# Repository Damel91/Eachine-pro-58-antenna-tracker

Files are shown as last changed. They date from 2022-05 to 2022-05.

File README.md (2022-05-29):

# Eachine-pro-58-antenna-tracker
A RSSI antenna tracker based on the eachine pro58

Tracker brain is the source for the arduino nano

wifi_firmware is the source for the esp8266

Into the PCB folder you can find the PCB wich is ready to use with the press and peel tecnique,
also you can find the pinout of the eachine pro 58

The 3D folder is a mess, go to thingiverse to find the freecad file to modify the project and see the entire project perspective https://www.thingiverse.com/thing:5397986/files

This antenna tracker is based on PID controller and single antenna tracking is experimental so use the manual settings

To configure the tracker use the GUI app that you need to install into your android smartphone

The project is designed also to work with a bmp280 module connected to the i2c bus

The analog pin of the ESP8266 is used to read the battery voltage, so use a trimmer to calibrate the voltage,
some esp8266 analog pin have 1V max others 3,3V, use the jumper to disconnect the trimmer output from the analog pin and calibrate the maximum voltage with the maximum level for the esp8266

The step down module can work from 2S LIPO to 6S LIPO and the code will automatically recognize the battery status and it's cell number, but of course you need to calibrate the trimmer with the maximum level of a 6S LIPO.

The gui will connect to the esp8266 through wifi since the esp8266 is configured as ap.

The antenna tracker mover vertically and horizzontally(wich is applied the actual pid tracking)

The servos used are two 9g

Also you need three 624ZZ ball bearings

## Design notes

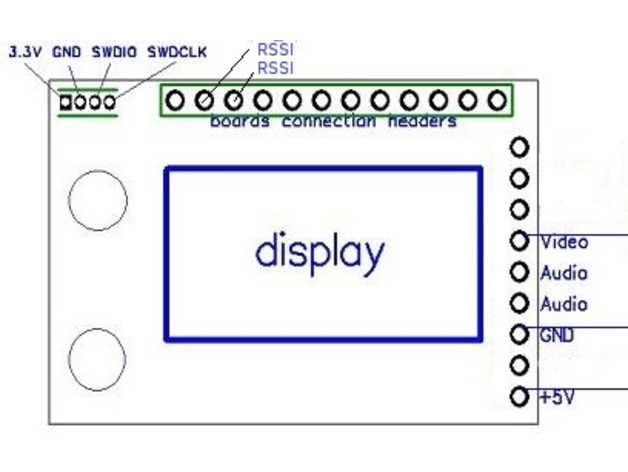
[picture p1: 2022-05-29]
PCB/eachine pro 58 pinout.jpg

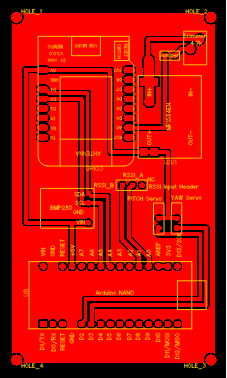
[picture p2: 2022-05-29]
PCB/PCB_antenna tracker_bottom_and_silk.png

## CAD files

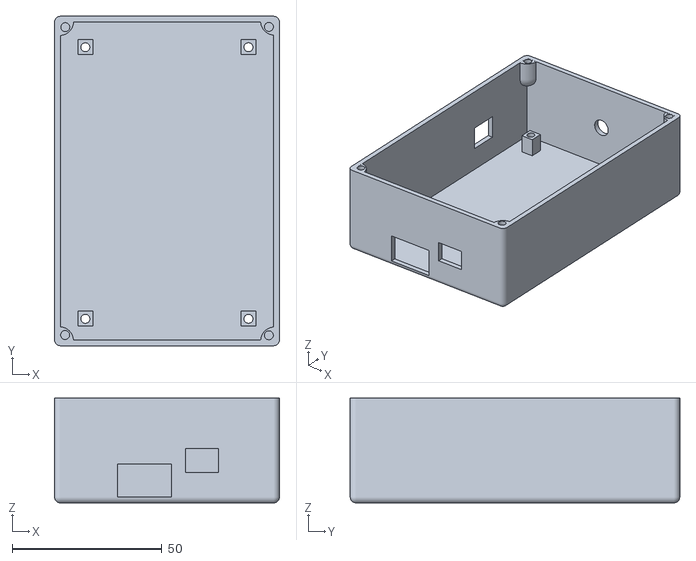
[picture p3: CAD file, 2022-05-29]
tracker 3d/tracker design-main box.stl
75.1 x 110.0 x 35.0

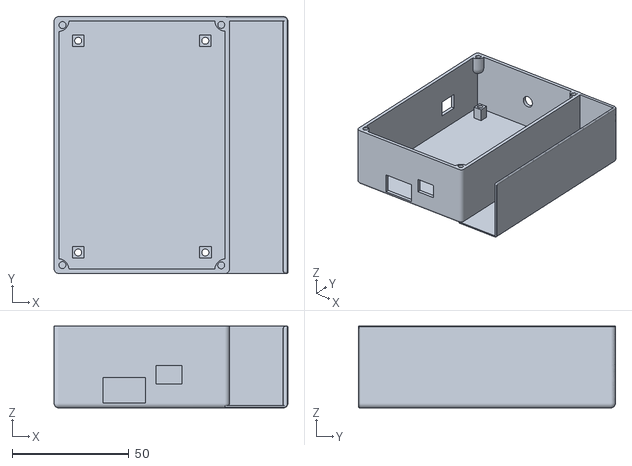
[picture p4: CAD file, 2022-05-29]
tracker 3d/tracker design-main box and battery holder.stl
100.1 x 110.0 x 35.0

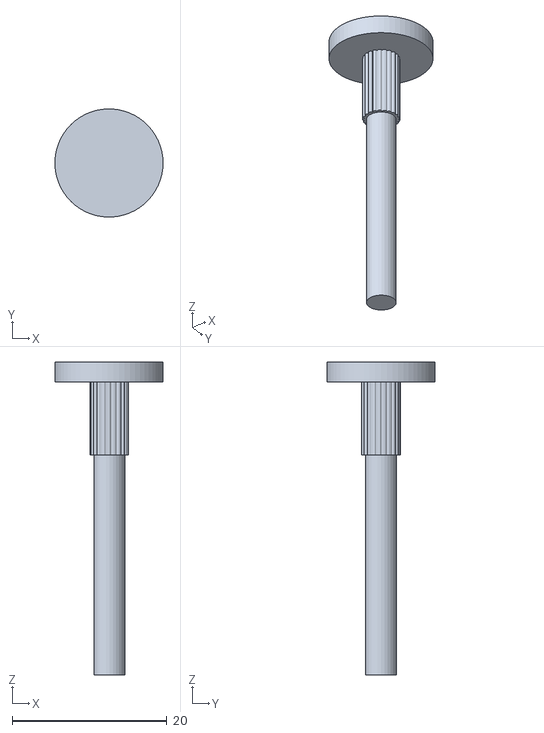
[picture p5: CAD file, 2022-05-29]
tracker 3d/tracker design-crankshaft_v2.stl
14.0 x 14.0 x 40.5

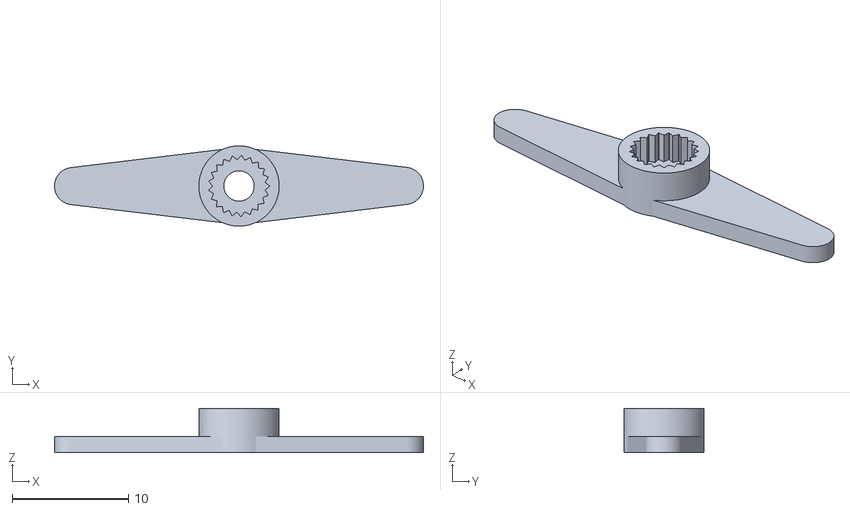
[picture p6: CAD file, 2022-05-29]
tracker 3d/SG90_Servo_Horn-4.stl
31.7 x 6.90 x 3.82

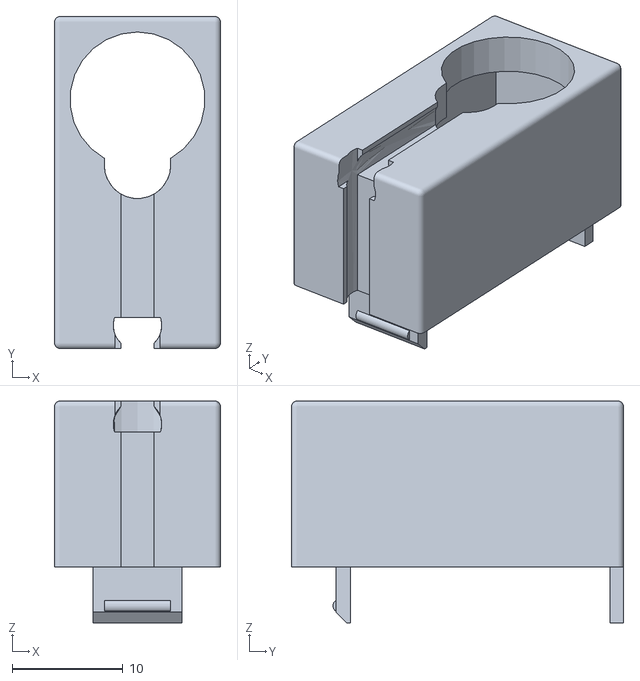
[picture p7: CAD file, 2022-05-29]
tracker 3d/Top_without_pegs_v21.stl
15.0 x 30.0 x 20.1

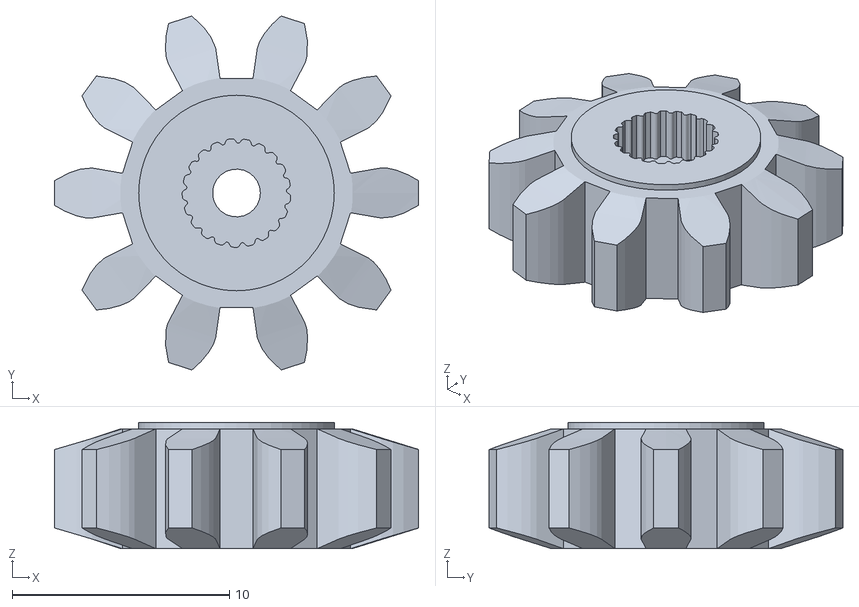
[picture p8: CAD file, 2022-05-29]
tracker 3d/03_Gear_Z10_adapter_v2.stl
16.8 x 16.3 x 5.80

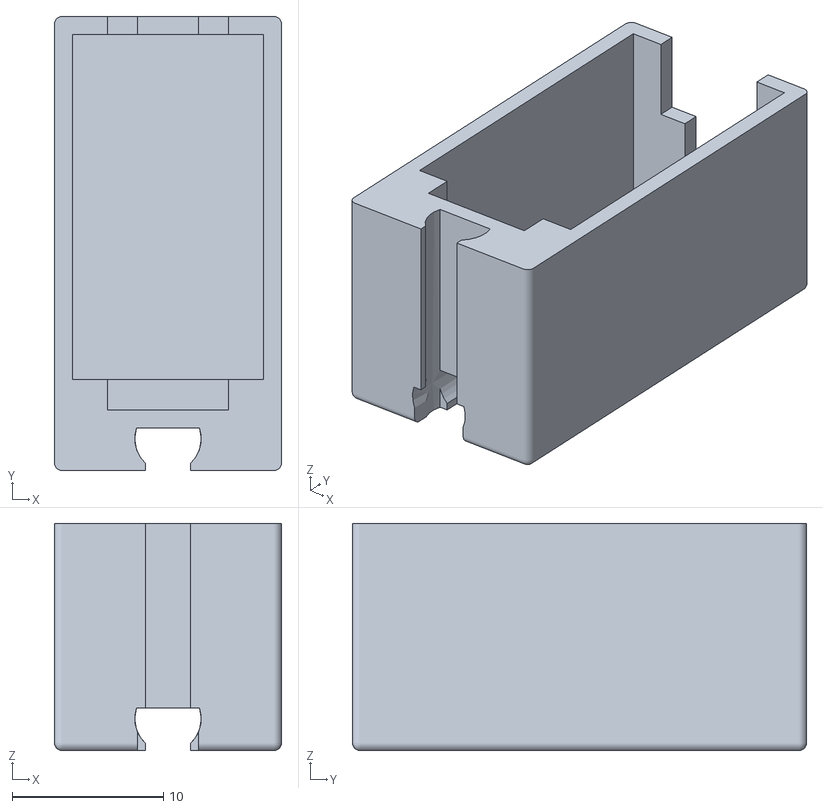
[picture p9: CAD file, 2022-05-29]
tracker 3d/Bottom_without_pegs_v21.stl
15.0 x 30.0 x 15.0

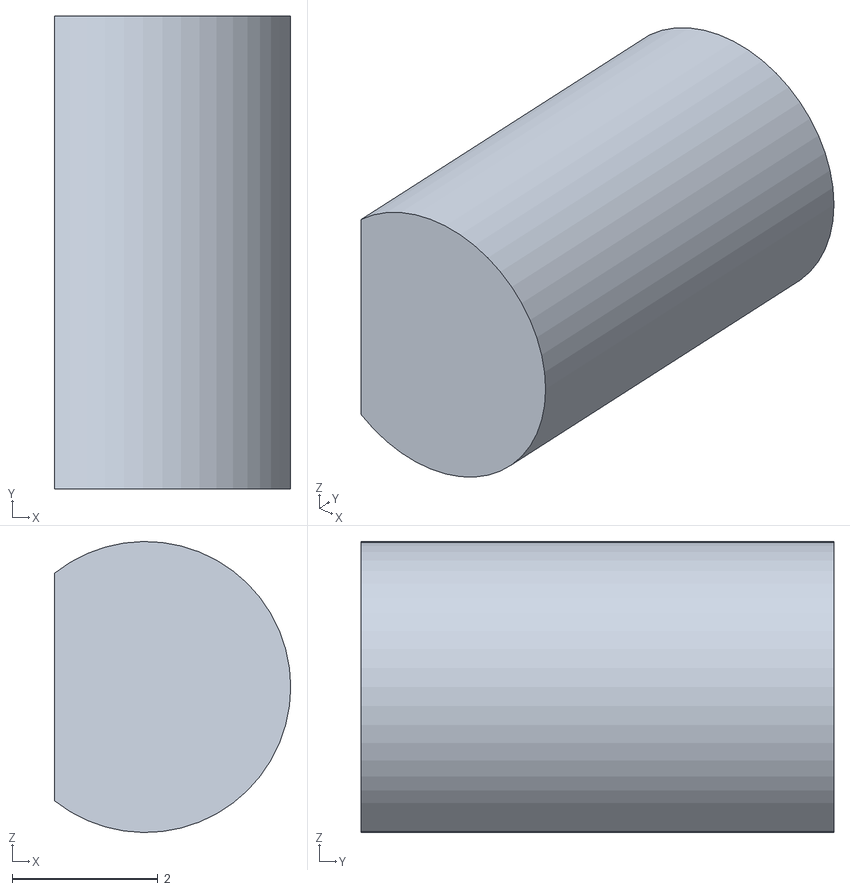
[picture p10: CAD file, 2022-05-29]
tracker 3d/tracker design-parts.stl
3.25 x 6.50 x 4.00

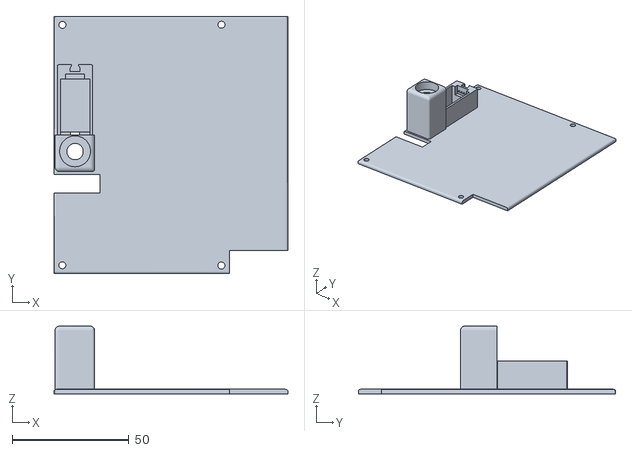
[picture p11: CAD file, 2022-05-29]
tracker 3d/tracker design-top_v2.stl
100.0 x 110.0 x 29.0

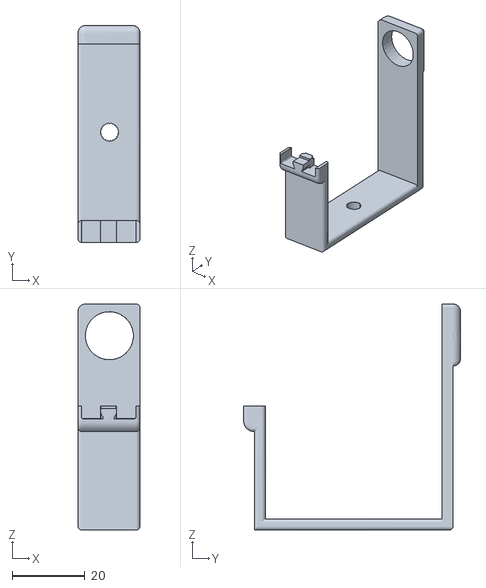
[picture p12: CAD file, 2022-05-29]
tracker 3d/tracker design-yawarm_v2.stl
17.0 x 59.5 x 62.0

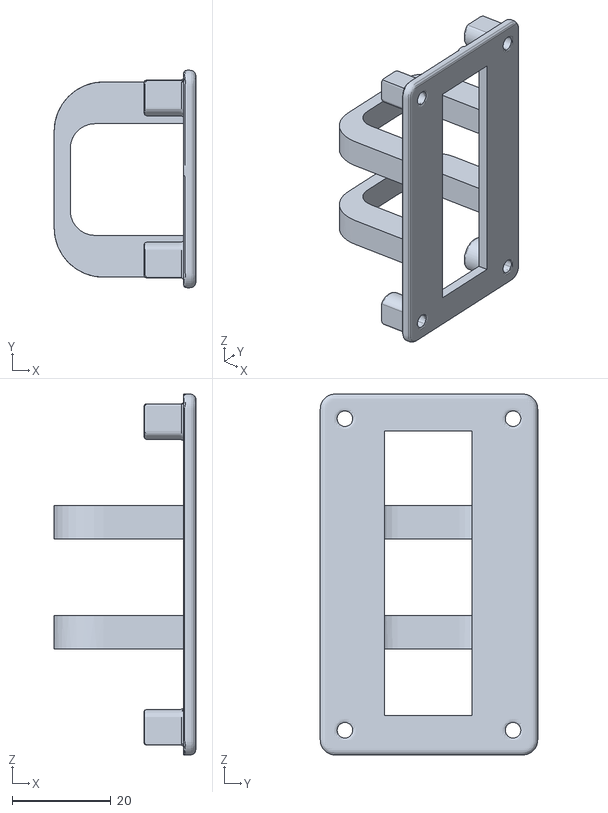
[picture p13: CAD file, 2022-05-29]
tracker 3d/tracker design-backcover_v2.stl
28.7 x 44.0 x 73.0

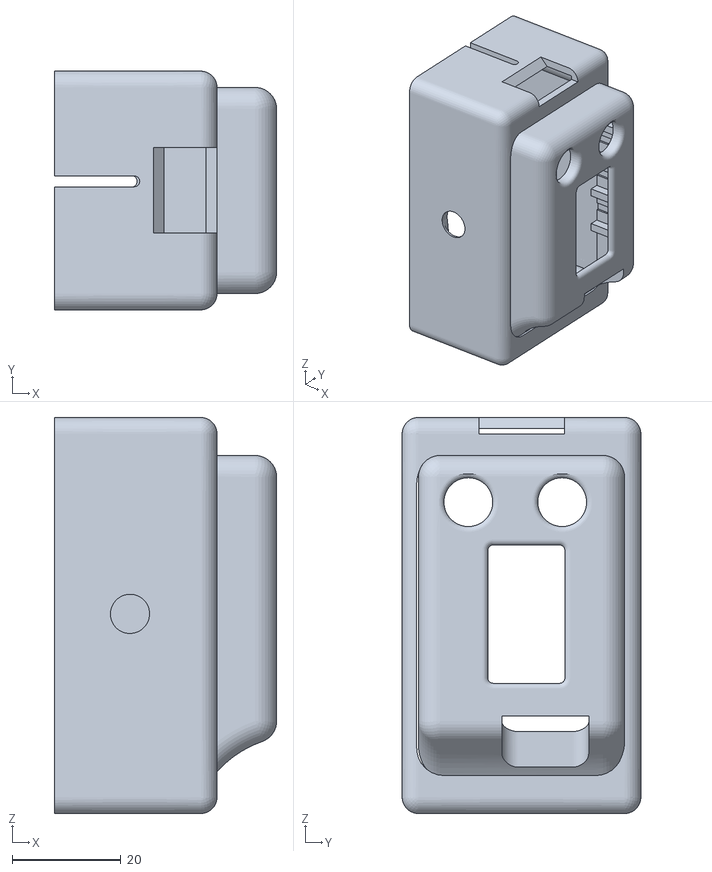
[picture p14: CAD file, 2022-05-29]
tracker 3d/tracker design-box to print_v2.stl
41.0 x 44.0 x 73.0

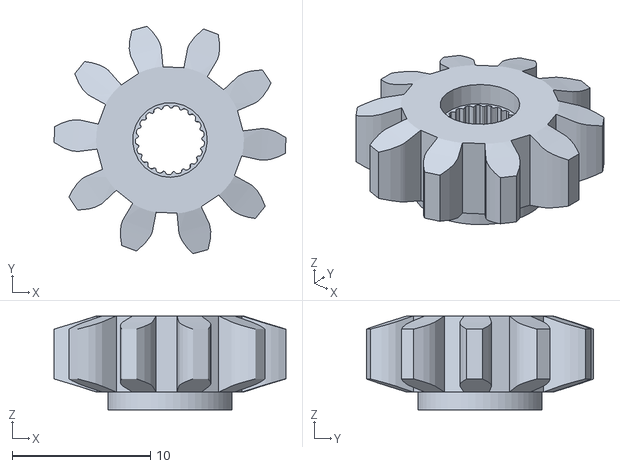
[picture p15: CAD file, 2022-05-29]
tracker 3d/tracker design-gearshaft001.stl
16.8 x 16.5 x 6.80

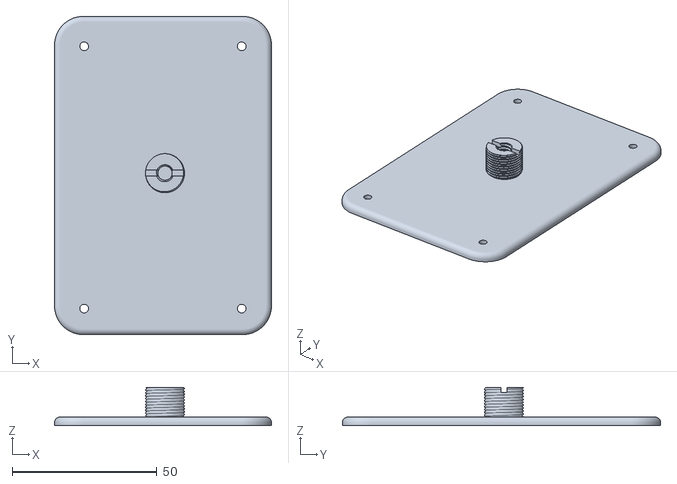
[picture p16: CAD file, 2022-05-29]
tracker 3d/tracker design-bottom.stl
75.0 x 110.0 x 13.3

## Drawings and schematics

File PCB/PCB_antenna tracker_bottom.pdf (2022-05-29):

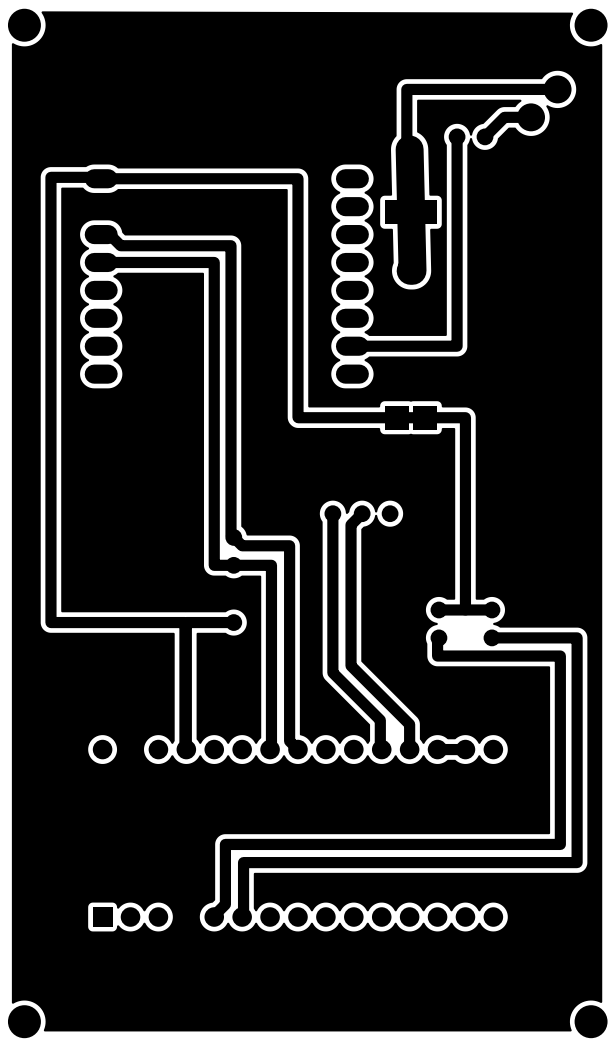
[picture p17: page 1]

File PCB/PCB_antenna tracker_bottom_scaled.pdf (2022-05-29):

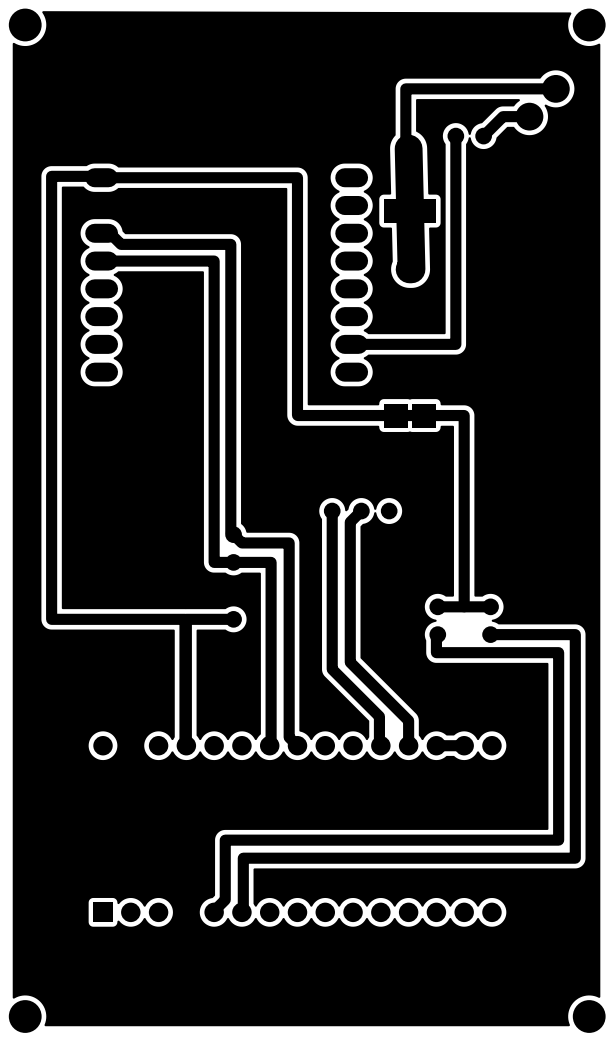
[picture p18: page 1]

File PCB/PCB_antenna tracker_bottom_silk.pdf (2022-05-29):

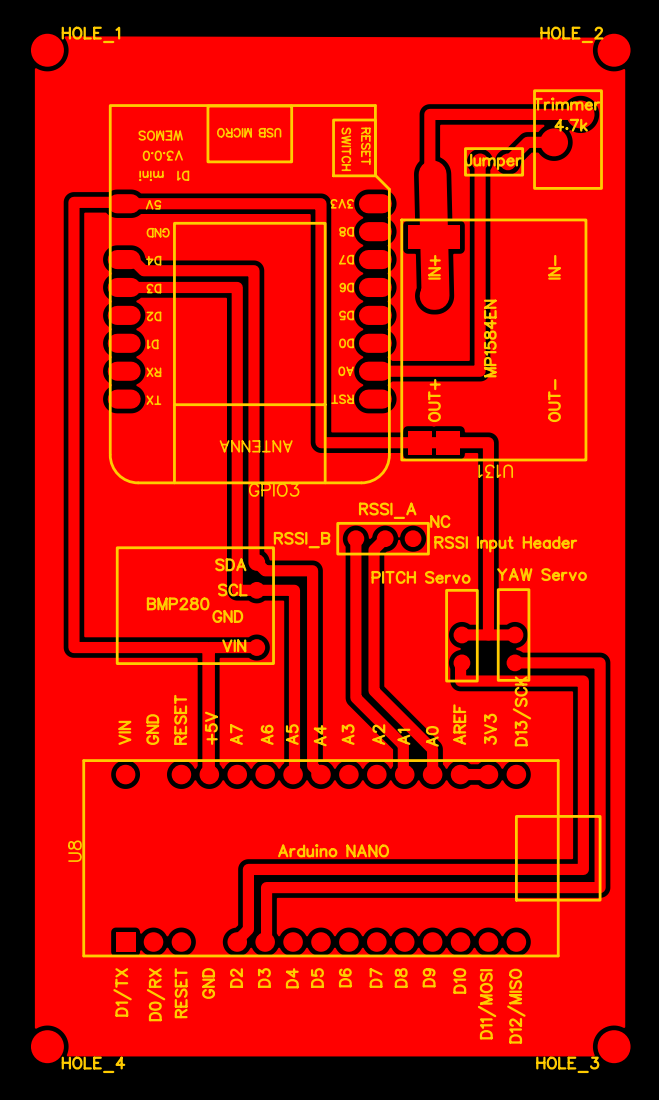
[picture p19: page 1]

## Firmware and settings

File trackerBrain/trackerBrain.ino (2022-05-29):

#include <EEPROM.h>
#include <PID_v1.h>
#include <Servo.h>
#include <Wire.h>
#define analogInPinA 22
#define analogInPinB 23
#define I2C_SLAVE 8

Servo pitchServo, yawServo;
int indexY = -1;
int indexP = -1;
int indexK = -1;
int indexI = -1;
int indexD = -1;
int indexM = -1;
int indexS = -1;
int indexV = -1;
int indexB = -1;
int opt = 0;
char a[21];
char b[21];
char c;
int rx = 0;
bool whoGoes = false;
bool request = false;
bool isReady = false;
String message= "N";
String receivedMessage = "";
int kpAddr = 0, kiAddr = 1, kdAddr = 2, offA = 3, offB = 4, modeAddr = 5, vertAddr = 6, deadBandAddr = 7;
//Define Variables we'll be connecting to
double Setpoint, Input, Output;

//Specify the links and initial tuning parameters
double Kp=0.1, Ki=0.5, Kd=0.7;
int kP, kI, kD;

PID myPID(&Input, &Output, &Setpoint, Kp, Ki, Kd, DIRECT);

bool go = false;
bool received = false;

bool precPitchDirection = false;
bool precYawDirection = false;

bool firstCalibration = false;

bool yawDirection = false;
bool pitchDirection = false;

bool lockPitch = false;
bool lockYaw = true;

int diff = 0;

int posCounterYaw = 90;
int posCounterPitch = 95;

int stepPitch = 0;
int stepYaw = 0;

int trackerMode = 0;
int precTrackerMode = 0;
int isVerticalTracking = 1;

int pinAOffset = 0;
int pinBOffset = 0;

int countPitch = 0;
int countYaw = 0;
int countRead = 0;

int analA, rawAnalA;
int analB, rawAnalB;
double averageA = 0;
double averageB = 0;

int yawPos = 90;
int pitchPos = 95;

int precPitch = 0;
int precYaw = 0;

unsigned long timeToWaitYaw = 30;
unsigned long timeToWaitPitch = 30;

unsigned long timeToWaitMessage = 100;
unsigned long messageTimer = 0;

unsigned long pitchCountMax = timeToWaitPitch;
unsigned long yawCountMax = timeToWaitYaw;

unsigned long now;
unsigned long precRead = 0;

unsigned long pitchTimer = 0;
unsigned long yawTimer = 0;

int stepYawCount = 20;
int stepPitchCount = 20;

int maxRSSIYaw = 0;
int maxRSSIPitch = 0;
int precRSSIYaw = 0;
int precRSSIPitch = 0;

int maxRSSI = 0;

int offset = 2;
int deadBand = 10;


void setup() {
  analogReference(EXTERNAL);
  // initialize serial communications at 9600 bps:
  Serial.begin(115200);
  Wire.begin(I2C_SLAVE);
  message.toCharArray(b, 21);
  Wire.onRequest(requestEvent); // register event
  Wire.onReceive(receive);
  pitchServo.attach(2);
  yawServo.attach(3);
  pitchServo.write(95);
  yawServo.write(90);
  pinMode(analogInPinA, INPUT_PULLUP);
  pinMode(analogInPinB, INPUT_PULLUP);

  loadFromEEPROM();
  
  if(isVerticalTracking == 1)
    lockPitch = true;

  if(trackerMode < 3)
    lockYaw = true;
    
  Setpoint = 100;
  myPID.SetOutputLimits(5, 100);
  myPID.SetSampleTime(5);
  myPID.SetTunings(Kp, Ki, Kd);  

  //turn the PID on
  myPID.SetMode(AUTOMATIC);

  delay(2000);
}
void(* reset) (void) = 0;

void loop() {
  readRSSI();
  moveYaw();
  movePitch();
  manageReceive();
  manageSend();
}

void loadFromEEPROM(){
  kpAddr *= sizeof(int);
  kiAddr *= sizeof(int);
  kdAddr *= sizeof(int);
  offA *= sizeof(int);  
  offB *= sizeof(int);  
  modeAddr *= sizeof(int);
  vertAddr *= sizeof(int);
  deadBandAddr *= sizeof(int); 

  EEPROM.get(kpAddr, kP);
  EEPROM.get(kiAddr, kI);
  EEPROM.get(kdAddr, kD);
  EEPROM.get(offA, pinAOffset);
  EEPROM.get(offB, pinBOffset);
  EEPROM.get(modeAddr, trackerMode);
  EEPROM.get(vertAddr, isVerticalTracking);
  EEPROM.get(deadBandAddr, deadBand);
  
  Kp = kP/1000.00;
  Ki = kI/1000.00;
  Kd = kD/1000.00;
}

void saveToEEPROM(){
  update(kpAddr, kP);
  update(kiAddr, kI);
  update(kdAddr, kD);
  update(offA, pinAOffset);
  update(offB, pinBOffset);
  update(modeAddr, trackerMode);
  update(vertAddr, isVerticalTracking);
  update(deadBandAddr, deadBand);
}

void update(int addr, int val){
  int c = 0;
  if(EEPROM.get(addr, c) != val)
    EEPROM.put(addr, val);
}

void manageSend(){
  if(!request){
    if(whoGoes){
      whoGoes = false;
      message = String(analA)+"A"+String(analB)+"B"+String(yawPos)+"Y"+String(pitchPos)+"P"+String(kP)+"K";
    }else{
      whoGoes = true;
      message = String(kI)+"I"+String(kD)+"D"+String(trackerMode)+"M"+String(isVerticalTracking)+"V"+String(deadBand)+"C";
    }
    request = true;
    isReady = false;
    rx = 0;
  } else {
    if(rx < message.length()){
      a[rx] = message.charAt(rx);
      rx++;
    } else
      isReady = true;
  }
}

void manageReceive(){
  if(received){
    received = false;
    request = false;
    
    indexY = receivedMessage.indexOf('Y');
    indexP = receivedMessage.indexOf('P');
    indexK = receivedMessage.indexOf('K');
    indexI = receivedMessage.indexOf('I');
    indexD = receivedMessage.indexOf('D');
    indexM = receivedMessage.indexOf('M');
    indexS = receivedMessage.indexOf('S');
    indexV = receivedMessage.indexOf('V');
    indexB = receivedMessage.indexOf('B');

    if(indexK>=0){
      kP = receivedMessage.substring(0, indexK).toInt(); 
      kI = receivedMessage.substring(indexK+1, indexI).toInt();
      kD = receivedMessage.substring(indexI+1, indexD).toInt();
      Kp = kP/1000.00;
      Ki = kI/1000.00;
      Kd = kD/1000.00;
      myPID.SetTunings(Kp, Ki, Kd);
    }

    if(indexM>=0){
      trackerMode = receivedMessage.substring(0, indexM).toInt();   

      if(trackerMode > 0)
        go = true;
    }

    if(indexV>=0)
      isVerticalTracking = receivedMessage.substring(0, indexV).toInt();   

    if(isVerticalTracking == 0){
      if(indexP>=0)
        pitchPos = receivedMessage.substring(indexY+1, indexP).toInt();
      stepPitch = 1;
    } else {
        lockPitch = true;
        stepPitch = 0;
        countPitch = 0;
        pitchCountMax = timeToWaitPitch;      
    }

    if(trackerMode == 3){
      if(indexY>=0)
        yawPos = receivedMessage.substring(0, indexY).toInt();
      stepYaw = 1; 
    } else {
      lockYaw = true;
      stepYaw = 0;
      countYaw = 0;
      yawCountMax = timeToWaitYaw; 
    }
      
    if(indexS>=0){
      opt = receivedMessage.substring(0, indexS).toInt();
      if(opt == 1)
      saveToEEPROM();
  
      if(opt == 2)
        reset();
    
      if(opt == 3)
        calibration();     
    }

    if(indexB>=0)
      deadBand = receivedMessage.substring(0, indexB).toInt();

    receivedMessage = "";
  }
}

void requestEvent() {
  if(isReady)
    Wire.write(a);
  else
    Wire.write(b);
    
  request = false;
}

void receive(int howMany) {
  while (Wire.available())   // slave may send less than requested
  {
    c = Wire.read();    // receive a byte as character
    receivedMessage += String(c);
  }

  received = true;
}

void readRSSI(){
  now = micros();

  if(now - precRead >= 133){
    precRead = now;

    averageA += analogRead(analogInPinA);
    averageB += analogRead(analogInPinB);  
    
    if(countRead>=15){
      countRead = 0;
      
      averageA /= 15;
      averageB /= 15;
      
      rawAnalA = (int) averageA;
      rawAnalB = (int) averageB;
    
      analA = rawAnalA - pinAOffset;
      analB = rawAnalB - pinBOffset;
  
      averageA = 0;
      averageB = 0;
    
      if(analA>analB){
        diff =(analA-analB);
        maxRSSI = analA;
        maxRSSIPitch = analB;
        if(trackerMode == 0)
          yawDirection = false;
      } else {
        diff =(analB-analA);
        maxRSSI = analB;
        maxRSSIPitch = analA;
        if(trackerMode == 0)
          yawDirection = true;
      }
    
      if(trackerMode == 0){
        Input = diff;
        myPID.Compute();
        timeToWaitYaw = (int) Output;
        if(diff < deadBand || maxRSSI<175){
          lockPitch = true;
          go = false;
        } else {
          go = true;
          lockPitch = false;
        }
      } else if(trackerMode < 3)
        timeToWaitYaw = timeToWaitPitch;
        else
        timeToWaitYaw = timeToWaitPitch;
      
      if(trackerMode == 1){
        maxRSSIYaw = analA;
        maxRSSIPitch = analA;
      }
    
      if(trackerMode == 2){
        maxRSSIYaw =  analB;
        maxRSSIPitch = analB;
      }
    } else
      countRead++;
  }
}

void movePitch(){
  now = millis();

  if(now-pitchTimer >= timeToWaitPitch){
    pitchTimer = now;

    if(isVerticalTracking)
      countPitch++;
    else
      countPitch = 0;

    if(stepPitch == 0 && lockPitch && countPitch >= pitchCountMax){

      countPitch = 0;
      lockYaw = false;
      stepPitch = 1;
      precRSSIPitch = maxRSSIPitch;
  
      if(pitchDirection){
        if(pitchPos>120)
          pitchPos =  posCounterPitch - 3;
        else
          pitchPos =  posCounterPitch - 2;
      }
      else
        pitchPos =  posCounterPitch + 2;
      
      if(pitchPos<=70)
        pitchPos = 70;
  
      if(pitchPos>=160)
        pitchPos = 160;

      if(precPitchDirection == pitchDirection)
        pitchCountMax -= timeToWaitPitch;

      if(pitchCountMax < 0)
        pitchCountMax = 0;

      precPitchDirection = pitchDirection;
    }
          

    if(stepPitch > 1 && stepPitch<stepPitchCount){
      stepPitch++;
    }

    if(stepPitch == 1){

      if(maxRSSIPitch > precRSSIPitch)
        precPitch = posCounterPitch;
      
      if(pitchPos > posCounterPitch)
        posCounterPitch++;
  
      if(pitchPos < posCounterPitch)
        posCounterPitch--;
  
      if(pitchPos == posCounterPitch)
        if(isVerticalTracking == 1)
          stepPitch = 2;
        else
          stepPitch = 1;
      
      if(posCounterPitch<=75)
        posCounterPitch = 75;
  
      if(posCounterPitch>=180)
        posCounterPitch = 180;
  
      pitchServo.write(posCounterPitch);
    }

    if(stepPitch >= stepPitchCount){

      if(posCounterPitch <= precPitch + offset && posCounterPitch >= precPitch - offset){
        pitchCountMax += timeToWaitPitch;
        pitchDirection != pitchDirection;
      } else {
        if(precPitch > posCounterPitch)
          pitchDirection = false;
      
        if(precPitch < posCounterPitch)
          pitchDirection = true;
      }

      if(posCounterPitch <= 75)
        pitchDirection = false;

      if (posCounterPitch>= 180)
        pitchDirection = true;
      
      stepPitch = 0;
      lockYaw = true;
    }
  }
}

void moveYaw(){
  now = millis();

  if(trackerMode == 0){
    if(now-yawTimer >= timeToWaitYaw && lockYaw && go){
      yawTimer = now;
      
      if(yawDirection && yawPos<180)
        yawPos++;
    
      if(!yawDirection && yawPos>0)
        yawPos--;

      posCounterYaw = yawPos;
    
      yawServo.write(yawPos);    
    }
  }

  if(trackerMode > 0){
    if(now-yawTimer >= timeToWaitYaw){
      yawTimer = now;

      if(trackerMode < 3)
        countYaw++;
      else
        countYaw = 0;
  
      if(stepYaw == 0 && lockYaw && countYaw >= yawCountMax){
        countYaw = 0;
        lockPitch = false;
        stepYaw = 1;
        precRSSIYaw = maxRSSIYaw;
    
        if(yawDirection)
          yawPos =  posCounterYaw - 3;
        else
          yawPos =  posCounterYaw + 3;
        
        if(yawPos<=0)
          yawPos = 0;
    
        if(yawPos>=180)
          yawPos = 180;
  
        if(precYawDirection == yawDirection)
          yawCountMax -= timeToWaitYaw;
  
        if(yawCountMax < 0)
          yawCountMax = 0;

        precYawDirection = yawDirection;
      }
            
  
      if(stepYaw > 1 && stepYaw<stepYawCount){
        stepYaw++;
      }
  
      if(stepYaw == 1){
  
        if(maxRSSIYaw > precRSSIYaw)
          precYaw = posCounterYaw;
        
        if(yawPos > posCounterYaw)
          posCounterYaw++;
    
        if(yawPos < posCounterYaw)
          posCounterYaw--;
    
        if(yawPos == posCounterYaw && trackerMode<3){
          stepYaw = 2;
        } else
          stepYaw = 1;
        
        if(posCounterYaw<=0)
          posCounterYaw = 0;
    
        if(posCounterYaw>=180)
          posCounterYaw = 180;
    
        yawServo.write(posCounterYaw);
      }
  
      if(stepYaw >= stepYawCount){
  
        if(posCounterYaw <= precYaw + offset && posCounterYaw >= precYaw - offset){
          yawCountMax += timeToWaitYaw;
          yawDirection != yawDirection;
        } else {
          if(precYaw > posCounterYaw)
            yawDirection = true;
        
          if(precYaw < posCounterYaw)
            yawDirection = false;
        }

      if(posCounterYaw <= 0)
        yawDirection = true;

      if (posCounterYaw>= 180)
        yawDirection = false;
        
        stepYaw = 0;
        lockPitch = true;
      }
    }
  }
}

void calibration(){
  if(rawAnalA>rawAnalB){
    pinAOffset =(rawAnalA-rawAnalB);
    pinBOffset = 0;
  }
   else {
    pinBOffset =(rawAnalB-rawAnalA);
    pinAOffset = 0;
 }
}

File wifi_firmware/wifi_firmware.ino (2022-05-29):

#include <ArduinoJson.h>
#include <ESPAsyncTCP.h>
#include <ESPAsyncWebServer.h>
#include <ESP8266WiFi.h>
#include <Wire.h>
#include <BMx280I2C.h>
#include <ESP8266mDNS.h>

#define I2C_ADDRESS 0x76
#define I2C_SLAVE 8 //Arduino nano register
#define SDA_PIN D4
#define SCL_PIN D3

String message, txMessage;
char a[15];

//create a BMx280I2C object using the I2C interface with I2C Address 0x76
BMx280I2C bmx280(I2C_ADDRESS);
double batteryValue = 0;
double cellVoltage = 0;
int batteryCellCount = 0;
int batteryStatus = 0;
int val = 0;
int RSSIA = 0;
int RSSIB = 0;
double pressure = 0.00;
double temperature = 0.00;
double altitude = 0.00;
bool whoGoes = false;

int trackerMode = 0, pitchPos = 0, yawPos = 0, kP = 0, kI = 0, kD = 0, isVerticalTracking = 0, deadBand = 0;

unsigned long batteryTimer = 0, trackerTimer = 0, barometerTimer = 0;
unsigned long timeToWait = 500;
 
// Set AP credentials
#define AP_SSID "TrackerGroundStation"
#define AP_PASS "pass_word"

const char* HOSTNAME = "antenna_tracker";

AsyncWebServer server(80); //Server on port 80

void setup() {
  // put your setup code here, to run once:
  Serial.begin(115200);
  Wire.begin(SDA_PIN, SCL_PIN);
  Wire.setClock(400000L);
  wifiConfig();
  baroConfig();
  serverResource();
}

void loop() {
  checkBattery();
  checkBarometer();
  checkTracker();
}

void checkBattery(){
  unsigned long now = millis();
  if(now - batteryTimer > timeToWait){
    batteryTimer = now;
    int val = analogRead(A0);
    batteryValue = val/40.5952380952;
    batteryCellCount = abs(batteryValue / 3.501);
    if(batteryCellCount > 6)
      batteryCellCount--;
      
    cellVoltage = batteryValue / batteryCellCount;
    double minVoltage = batteryCellCount * 3.5;
    double maxVoltage = batteryCellCount * 4.2;
    batteryStatus = (batteryValue - minVoltage) / (maxVoltage - minVoltage) * 100;
  }
}

void checkBarometer(){
  unsigned long now = millis();
  //start a measurement
  if (!bmx280.measure() && (now - barometerTimer <= timeToWait))
    return;

  barometerTimer = now;
    
  if(bmx280.hasValue()){
    pressure = bmx280.getPressure64();
    temperature = bmx280.getTemperature();
    altitude = 44330 * (1 - pow((bmx280.getPressure()/101325.00),(1/5.255)));
  }
}

void checkTracker(){
  unsigned long now = millis();
  if(now - trackerTimer > 150){
    trackerTimer = now;
    if(whoGoes){
      sendMessage();
      whoGoes = false;
    }
    else
      Receive();
  }
}

void Receive() {
  Wire.requestFrom(I2C_SLAVE, 21);
  
  char c;
  message = "";
  while (Wire.available())   // slave may send less than requested
  {
    c = Wire.read();    // receive a byte as character
    message = message + String(c);
  }

  Serial.println(message);

  int indexN = message.indexOf('N');
  int indexA = message.indexOf('A');
  int indexB = message.indexOf('B');
  int indexY = message.indexOf('Y');
  int indexP = message.indexOf('P');
  int indexK = message.indexOf('K');
  int indexI = message.indexOf('I');
  int indexD = message.indexOf('D');
  int indexM = message.indexOf('M');
  int indexV = message.indexOf('V');
  int indexC = message.indexOf('C');

  if(indexN<0){
    if(indexI<0){
      RSSIA = message.substring(0, indexA).toInt();
      RSSIB = message.substring(indexA+1, indexB).toInt();
      yawPos = message.substring(indexB+1, indexY).toInt();
      pitchPos = message.substring(indexY+1, indexP).toInt();
      kP = message.substring(indexP+1, indexK).toInt(); 
    } else {
      kI = message.substring(0, indexI).toInt();
      kD = message.substring(indexI+1, indexD).toInt();
      trackerMode = message.substring(indexD+1, indexM).toInt();
      isVerticalTracking = message.substring(indexM+1, indexV).toInt();
      deadBand = message.substring(indexV+1, indexC).toInt();
    }   
  }
}

void sendMessage() {
  Wire.beginTransmission(I2C_SLAVE); // transmit to device #8
  Wire.write(a);        
  Wire.endTransmission();    // stop transmitting
}


void wifiConfig(){
  // Begin Access Point
  WiFi.softAP(AP_SSID, AP_PASS);
  WiFi.setHostname(HOSTNAME);

}

void baroConfig(){
  //begin() checks the Interface, reads the sensor ID (to differentiate between BMP280 and BME280)
  //and reads compensation parameters.
  if (!bmx280.begin())
  {
    //Serial.println("begin() failed. check your BMx280 Interface and I2C Address.");
    while (1);
  }

  //reset sensor to default parameters.
  bmx280.resetToDefaults();

  //by default sensing is disabled and must be enabled by setting a non-zero
  //oversampling setting.
  //set an oversampling setting for pressure and temperature measurements. 
  bmx280.writeOversamplingPressure(BMx280MI::OSRS_P_x16);
  bmx280.writeOversamplingTemperature(BMx280MI::OSRS_T_x16);
}


void serverResource(){
  if (!MDNS.begin(HOSTNAME)){
    return;
  }
  MDNS.addService("http", "tcp", 80);
        
  server.on("/getLoad", HTTP_GET, [](AsyncWebServerRequest * request) {
    DynamicJsonDocument doc(1024);
    doc["batteryInfo"][0] = batteryValue;
    doc["batteryInfo"][1] = cellVoltage;
    doc["batteryInfo"][2] = batteryCellCount;
    doc["batteryInfo"][3] = batteryStatus;
    doc["barometerInfo"][0] = pressure;
    doc["barometerInfo"][1] = altitude;
    doc["barometerInfo"][2] = temperature;
    doc["trackerInfo"][0] = trackerMode;
    doc["trackerInfo"][1] = pitchPos;
    doc["trackerInfo"][2] = yawPos;
    doc["trackerInfo"][3] = RSSIA;
    doc["trackerInfo"][4] = RSSIB;
    doc["trackerInfo"][5] = kP;
    doc["trackerInfo"][6] = kI;
    doc["trackerInfo"][7] = kD;
    doc["trackerInfo"][8] = isVerticalTracking;
    doc["trackerInfo"][9] = deadBand;
    
    String jsonData;
    serializeJson(doc, jsonData);
    request->send(200, "text/json", jsonData);
  });

  server.on("/sendToTracker", HTTP_GET, [](AsyncWebServerRequest * request) {
    txMessage = request->getParam("testo")->value();
    txMessage.toCharArray(a, 15);
    whoGoes = true;
    request->send(200, "text/plain", txMessage);
  });

  DefaultHeaders::Instance().addHeader("Access-Control-Allow-Origin", "*");
  server.onNotFound(notFound);
  server.begin();
}

void notFound(AsyncWebServerRequest *request) {
  request->send(404, "text/plain", "Not found");
}

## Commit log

2022-05-29 new files
    [03_Gear_Z10_adapter_v2.stl, Bottom_without_pegs_v21.stl, SG90_Servo_Horn-4.stl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]
2022-05-29 Update antenna_tracker GUI.apk
